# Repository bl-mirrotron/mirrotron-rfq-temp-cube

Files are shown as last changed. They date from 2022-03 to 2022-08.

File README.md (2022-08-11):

# RFQ Temperature Cube
* <a href="https://github.com/bl-mirrotron/mirrotron-rfq-temp-cube" target="_blank">Source code</a>
* [Cooling system overview](https://docs.bl-mirrotron.com/#cooling-system)
* [Control system overview](https://docs.bl-mirrotron.com/)

The function of the RFQ Temperature Cube is to measure the temperature of the cooling channels on both the upstream and downstream headers. The temperature is measured with <a href="https://www.maximintegrated.com/en/products/sensors/DS18B20.html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,for%20an%20external%20power%20supply." target="_blank">DS18B20</a> One-wire probes connected to a <a href="https://www.pjrc.com/teensy/teensyLC.html" target="_blank">Teensy-LC</a> as the micro-controller. The Teensy-LC communicates to a Blinky-Lite<sup>TM</sup> tray via the <a href="https://github.com/bl-mirrotron/mirrotron-rfq-temp-cube/blob/master/cubeCode/BlinkyBus.h" target="_blank">Blinky-Bus protocol</a> over the Serial1 port.

The schematic for the electrical circuit is shown in Figure 1. The board is designed to handle up to eight probes with each probe having it's own on/off power control if a individual channel needs a reboot. The PCB layout for the electrical circuit is shown in Figure 2. There is a 2x20 pin header mounted on the back of the PCB so that the cube can be directly mounted to a Raspberry Pi header for power and communications. 5V power to the Teensy-LC is provided through the header from Raspberry Pi. A manufactured board is shown in Figure 3.

<p style="text-align:center;font-size: large;"><span style="font-weight: bold;color: green;">Figure 1. </span> <span style="font-style: italic;">Electrical Schematic for rfq-temp-cube board</span></p>
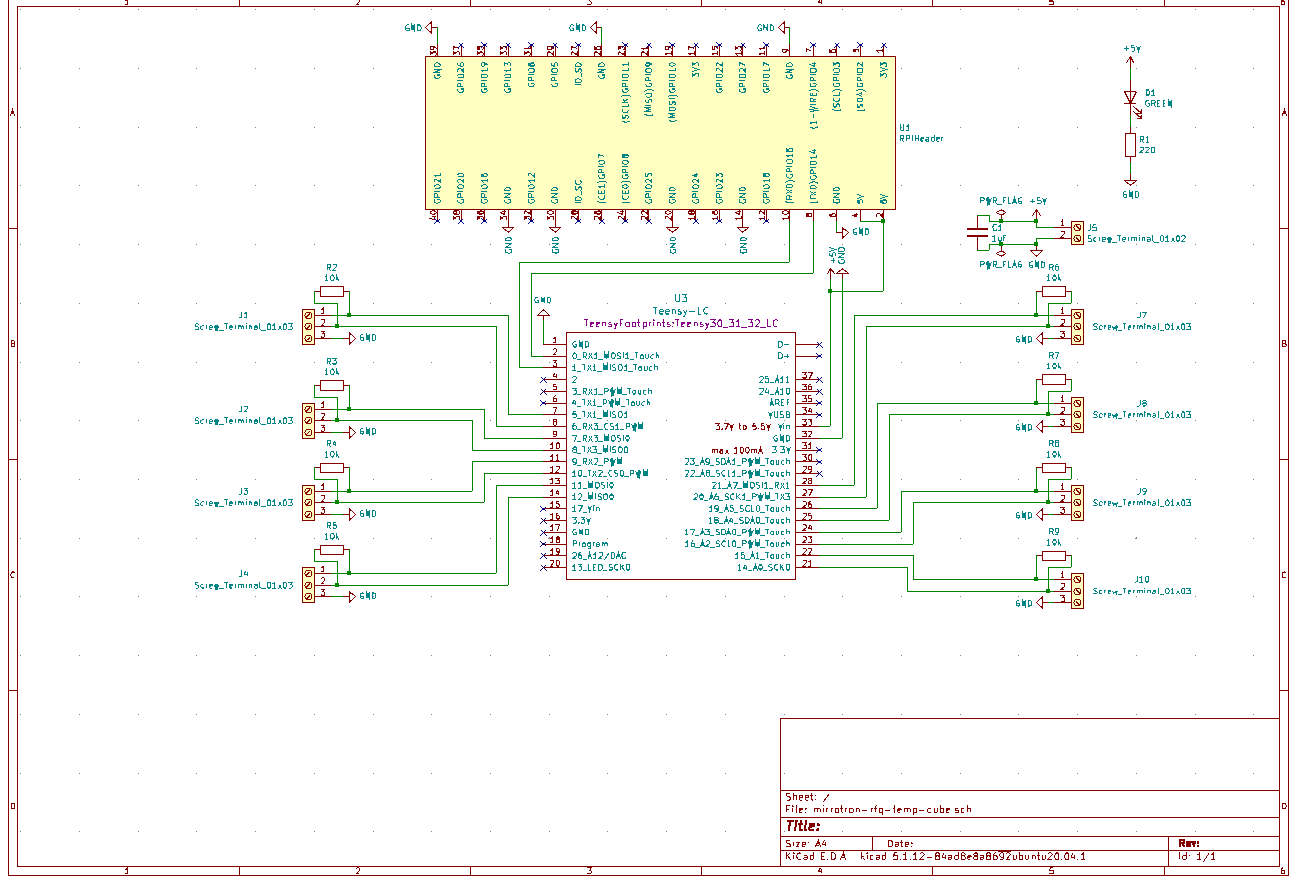
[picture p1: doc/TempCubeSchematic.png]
<br>

<p style="text-align:center;font-size: large;"><span style="font-weight: bold;color: green;">Figure 2. </span> <span style="font-style: italic;">PCB layout for rfq-temp-cube board</span></p>
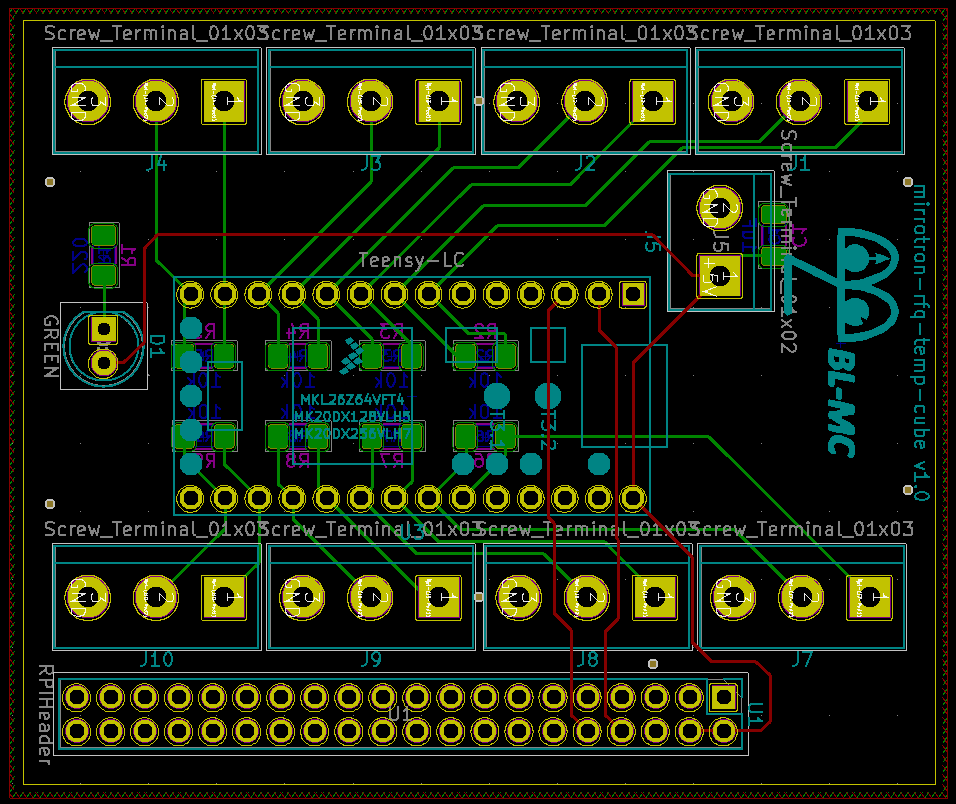
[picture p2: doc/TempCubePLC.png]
<br>

<p style="text-align:center;font-size: large;"><span style="font-weight: bold;color: green;">Figure 3. </span> <span style="font-style: italic;">rfq-temp-cube</span></p>
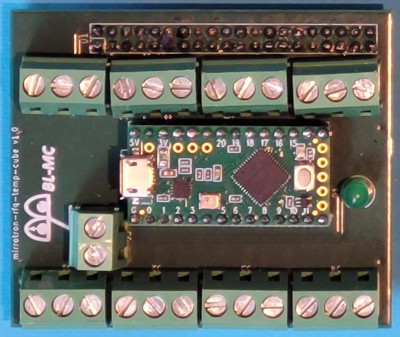
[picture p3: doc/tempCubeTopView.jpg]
<br>

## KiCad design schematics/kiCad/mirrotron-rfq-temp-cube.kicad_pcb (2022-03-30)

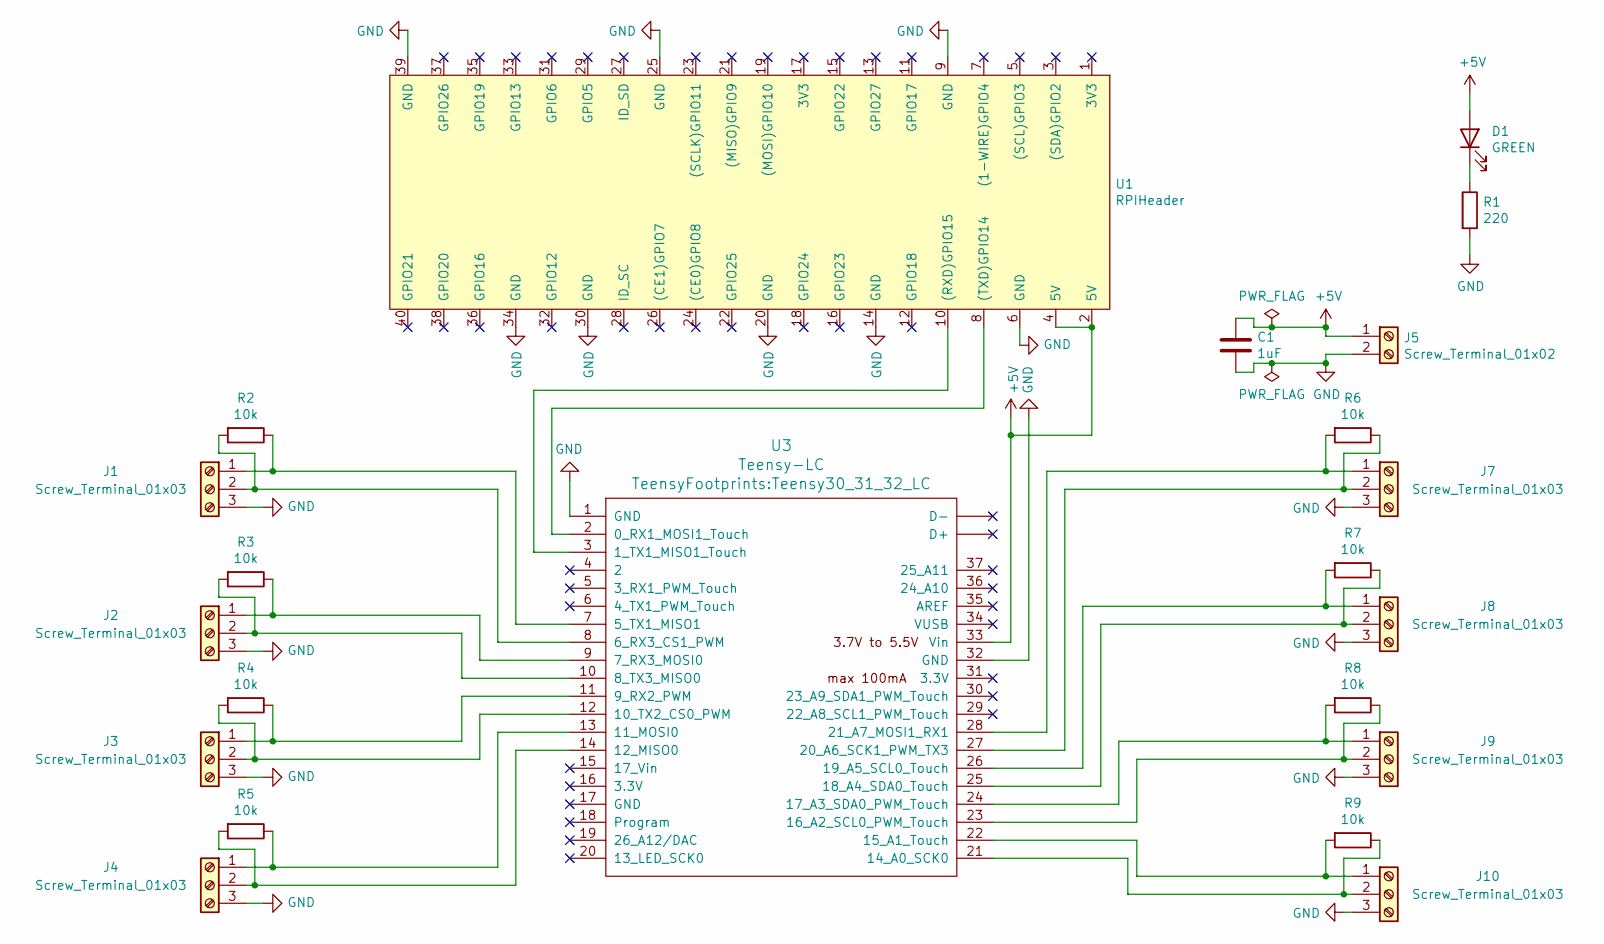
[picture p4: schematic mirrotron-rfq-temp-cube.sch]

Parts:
C1: 1uF; C_1206_3216Metric_Pad1.33x1.80mm_HandSolder
D1: GREEN; LED_D5.0mm
J1, J2, J3, J4, J7, J8, J9, J10: Screw_Terminal_01x03; TerminalBlock_bornier-3_P5.08mm
J5: Screw_Terminal_01x02; TerminalBlock_bornier-2_P5.08mm
R1: 220; R_1206_3216Metric_Pad1.42x1.75mm_HandSolder
R2, R3, R4, R5, R6, R7, R8, R9: 10k; R_1206_3216Metric_Pad1.42x1.75mm_HandSolder
U1: RPIHeader; PinHeader_2x20_P2.54mm_Vertical
U3: Teensy-LC; Teensy30_31_32_LC

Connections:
+5V: C1.1, D1.2 (A), J5.1, U1.2 (5V), U1.4 (5V), U3.33 (Vin)
GND: C1.2, J1.3, J2.3, J3.3, J4.3, J5.2, J7.3, J8.3, J9.3, J10.3, R1.2, U1.6 (GND), U1.9 (GND), U1.14 (GND), U1.20 (GND), U1.25 (GND), U1.30 (GND), U1.34 (GND), U1.39 (GND), U3.1 (GND), U3.32 (GND)
unnamed: D1.1 (K), R1.1
unnamed: J1.1, R2.1, U3.7 (5_TX1_MISO1)
unnamed: J1.2, R2.2, U3.8 (6_RX3_CS1_PWM)
unnamed: J2.1, R3.1, U3.9 (7_RX3_MOSI0)
unnamed: J2.2, R3.2, U3.10 (8_TX3_MISO0)
unnamed: J3.1, R4.1, U3.11 (9_RX2_PWM)
unnamed: J3.2, R4.2, U3.12 (10_TX2_CS0_PWM)
unnamed: J4.1, R5.1, U3.13 (11_MOSI0)
unnamed: J4.2, R5.2, U3.14 (12_MISO0)
unnamed: J7.1, R6.2, U3.28 (21_A7_MOSI1_RX1)
unnamed: J7.2, R6.1, U3.27 (20_A6_SCK1_PWM_TX3)
unnamed: J8.1, R7.2, U3.26 (19_A5_SCL0_Touch)
unnamed: J8.2, R7.1, U3.25 (18_A4_SDA0_Touch)
unnamed: J9.1, R8.2, U3.24 (17_A3_SDA0_PWM_Touch)
unnamed: J9.2, R8.1, U3.23 (16_A2_SCL0_PWM_Touch)
unnamed: J10.1, R9.2, U3.22 (15_A1_Touch)
unnamed: J10.2, R9.1, U3.21 (14_A0_SCK0)
unnamed: U1.8 ((TXD)GPIO14), U3.2 (0_RX1_MOSI1_Touch)
unnamed: U1.10 ((RXD)GPIO15), U3.3 (1_TX1_MISO1_Touch)

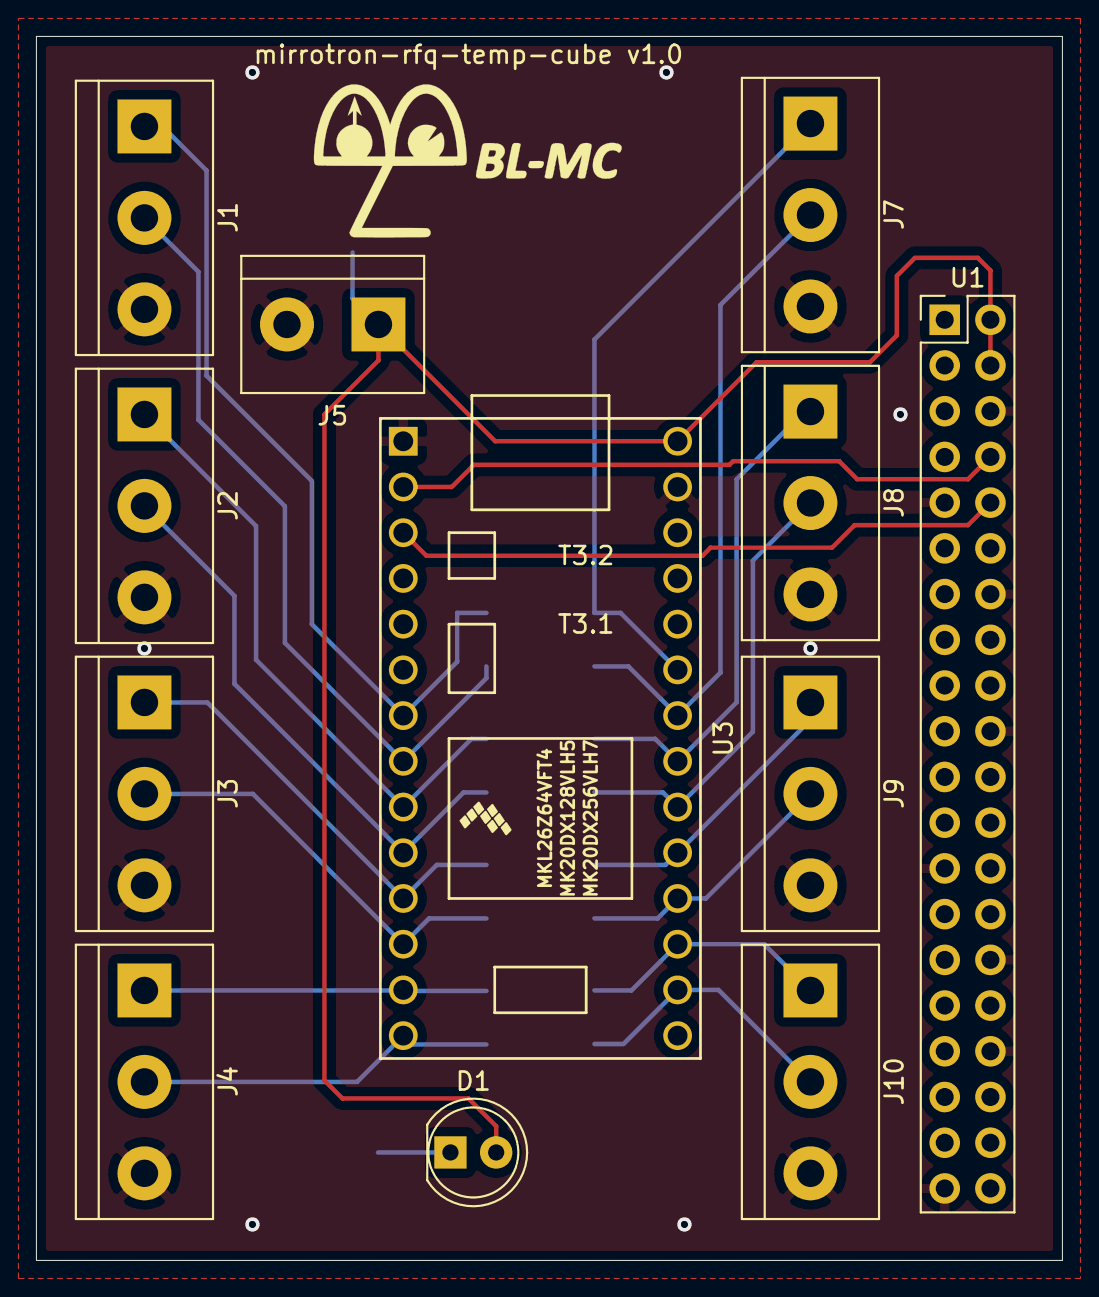
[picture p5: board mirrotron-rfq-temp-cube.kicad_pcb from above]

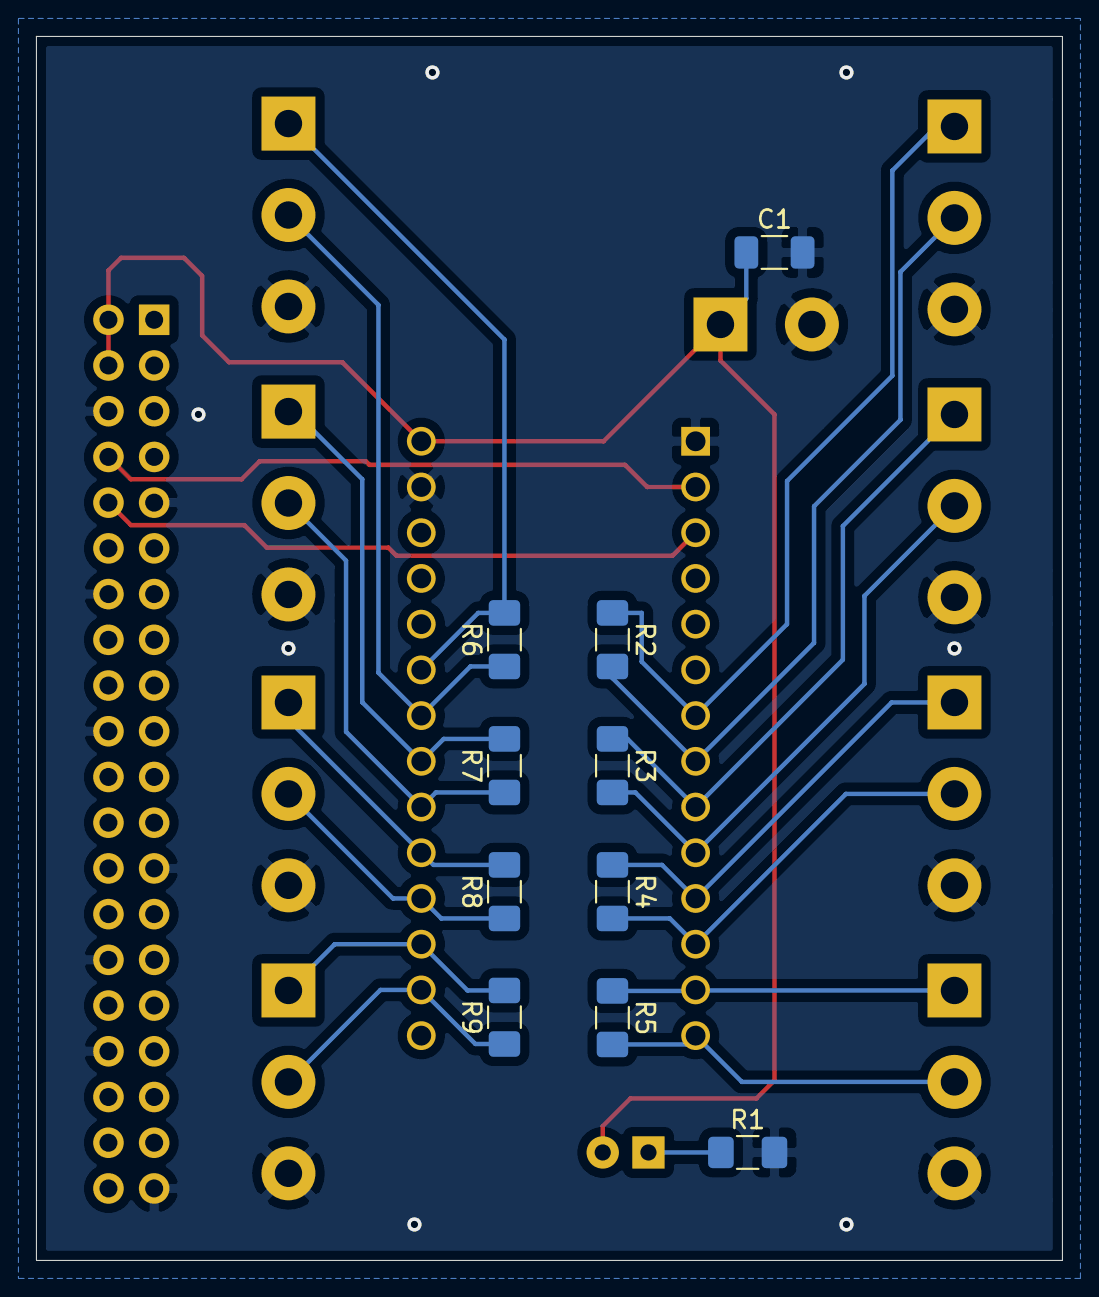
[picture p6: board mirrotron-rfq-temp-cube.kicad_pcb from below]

Board: 2 copper layers, 57.0 x 68.0 mm, 22 parts (10 on the bottom side), 21 nets.

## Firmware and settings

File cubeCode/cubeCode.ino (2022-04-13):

#include "BlinkyBus.h"
#include <OneWire.h>
#define BAUD_RATE  19200
#define commLEDPin    13
#define waitLOW 500
#define waitHIGH 500
#define waitMEAS 1000

#define BLINKYBUSBUFSIZE  10
union BlinkyBusUnion
{
  struct
  {
    int16_t state;
    int16_t i16_temp1;
    int16_t i16_temp2;
    int16_t i16_temp3;
    int16_t i16_temp4;
    int16_t i16_temp5;
    int16_t i16_temp6;
    int16_t i16_temp7;
    int16_t i16_temp8;
    int16_t i16_watchdog;
  };
  int16_t buffer[BLINKYBUSBUFSIZE];
} bb;
BlinkyBus blinkyBus(bb.buffer, BLINKYBUSBUFSIZE, Serial1, commLEDPin);

struct DS18B20
{
  int signalPin;
  int powerPin;
  byte chipType;
  byte address[8];
  OneWire oneWire;
  float temp = 0.0;
};

DS18B20 dS18B20_1;
DS18B20 dS18B20_2;
DS18B20 dS18B20_3;
DS18B20 dS18B20_4;
DS18B20 dS18B20_5;
DS18B20 dS18B20_6;
DS18B20 dS18B20_7;
DS18B20 dS18B20_8;

void setup() 
{
  dS18B20_1.signalPin = 6;
  dS18B20_1.powerPin = 5;
  pinMode(dS18B20_1.powerPin, OUTPUT);

  dS18B20_2.signalPin = 8;
  dS18B20_2.powerPin = 7;
  pinMode(dS18B20_2.powerPin, OUTPUT);
  digitalWrite(dS18B20_2.powerPin, HIGH);    

  dS18B20_3.signalPin = 10;
  dS18B20_3.powerPin = 9;
  pinMode(dS18B20_3.powerPin, OUTPUT);
  digitalWrite(dS18B20_3.powerPin, HIGH);    

  dS18B20_4.signalPin = 12;
  dS18B20_4.powerPin = 11;
  pinMode(dS18B20_4.powerPin, OUTPUT);
  digitalWrite(dS18B20_4.powerPin, HIGH);   

  dS18B20_5.signalPin = 14;
  dS18B20_5.powerPin = 15;
  pinMode(dS18B20_5.powerPin, OUTPUT);
  digitalWrite(dS18B20_5.powerPin, HIGH);   

  dS18B20_6.signalPin = 16;
  dS18B20_6.powerPin = 17;
  pinMode(dS18B20_6.powerPin, OUTPUT);
  digitalWrite(dS18B20_6.powerPin, HIGH);   

  dS18B20_7.signalPin = 18;
  dS18B20_7.powerPin = 19;
  pinMode(dS18B20_7.powerPin, OUTPUT);
  digitalWrite(dS18B20_7.powerPin, HIGH);   

  dS18B20_8.signalPin = 20;
  dS18B20_8.powerPin = 21;
  pinMode(dS18B20_8.powerPin, OUTPUT);
  digitalWrite(dS18B20_8.powerPin, HIGH);   

  digitalWrite(dS18B20_1.powerPin, LOW);    
  digitalWrite(dS18B20_2.powerPin, LOW);    
  digitalWrite(dS18B20_3.powerPin, LOW);    
  digitalWrite(dS18B20_4.powerPin, LOW);    
  digitalWrite(dS18B20_5.powerPin, LOW);    
  digitalWrite(dS18B20_6.powerPin, LOW);    
  digitalWrite(dS18B20_7.powerPin, LOW);    
  digitalWrite(dS18B20_8.powerPin, LOW);    
  delay(1000);
  digitalWrite(dS18B20_1.powerPin, HIGH);    
  digitalWrite(dS18B20_2.powerPin, HIGH);    
  digitalWrite(dS18B20_3.powerPin, HIGH);    
  digitalWrite(dS18B20_4.powerPin, HIGH);    
  digitalWrite(dS18B20_5.powerPin, HIGH);    
  digitalWrite(dS18B20_6.powerPin, HIGH);    
  digitalWrite(dS18B20_7.powerPin, HIGH);    
  digitalWrite(dS18B20_8.powerPin, HIGH);    
  delay(2000);

  dS18B20_1.oneWire = OneWire(dS18B20_1.signalPin);
  dS18B20_1.chipType = initDS18B20(dS18B20_1.address, &dS18B20_1.oneWire);
  dS18B20_2.oneWire = OneWire(dS18B20_2.signalPin);
  dS18B20_2.chipType = initDS18B20(dS18B20_2.address, &dS18B20_2.oneWire);
  dS18B20_3.oneWire = OneWire(dS18B20_3.signalPin);
  dS18B20_3.chipType = initDS18B20(dS18B20_3.address, &dS18B20_3.oneWire);
  dS18B20_4.oneWire = OneWire(dS18B20_4.signalPin);
  dS18B20_4.chipType = initDS18B20(dS18B20_4.address, &dS18B20_4.oneWire);
  dS18B20_5.oneWire = OneWire(dS18B20_5.signalPin);
  dS18B20_5.chipType = initDS18B20(dS18B20_5.address, &dS18B20_5.oneWire);
  dS18B20_6.oneWire = OneWire(dS18B20_6.signalPin);
  dS18B20_6.chipType = initDS18B20(dS18B20_6.address, &dS18B20_6.oneWire);
  dS18B20_7.oneWire = OneWire(dS18B20_7.signalPin);
  dS18B20_7.chipType = initDS18B20(dS18B20_7.address, &dS18B20_7.oneWire);
  dS18B20_8.oneWire = OneWire(dS18B20_8.signalPin);
  dS18B20_8.chipType = initDS18B20(dS18B20_8.address, &dS18B20_8.oneWire);

  
  Serial1.begin(BAUD_RATE);
  bb.state = 1; //init
  bb.i16_watchdog = 0; //init
  blinkyBus.start();
  delay(5000);
  
  Serial.begin(9600);

}

void loop() 
{
    digitalWrite(dS18B20_1.powerPin, LOW);
    waitSome(waitLOW);    
    digitalWrite(dS18B20_1.powerPin, HIGH);
    waitSome(waitHIGH);    
    dS18B20_1.temp = getDS18B20Temperature(&dS18B20_1.oneWire, dS18B20_1.address, dS18B20_1.chipType);
    bb.i16_temp1  = (int16_t) (dS18B20_1.temp * 10.0);

    digitalWrite(dS18B20_2.powerPin, LOW);
    waitSome(waitLOW);    
    digitalWrite(dS18B20_2.powerPin, HIGH);
    waitSome(waitHIGH);    
    dS18B20_2.temp = getDS18B20Temperature(&dS18B20_2.oneWire, dS18B20_2.address, dS18B20_2.chipType);
    bb.i16_temp2  = (int16_t) (dS18B20_2.temp * 10.0);

    digitalWrite(dS18B20_3.powerPin, LOW);
    waitSome(waitLOW);    
    digitalWrite(dS18B20_3.powerPin, HIGH);
    waitSome(waitHIGH);    
    dS18B20_3.temp = getDS18B20Temperature(&dS18B20_3.oneWire, dS18B20_3.address, dS18B20_3.chipType);
    bb.i16_temp3  = (int16_t) (dS18B20_3.temp * 10.0);

    digitalWrite(dS18B20_4.powerPin, LOW);
    waitSome(waitLOW);    
    digitalWrite(dS18B20_4.powerPin, HIGH);
    waitSome(waitHIGH);    
    dS18B20_4.temp = getDS18B20Temperature(&dS18B20_4.oneWire, dS18B20_4.address, dS18B20_4.chipType);
    bb.i16_temp4  = (int16_t) (dS18B20_4.temp * 10.0);

    digitalWrite(dS18B20_5.powerPin, LOW);
    waitSome(waitLOW);    
    digitalWrite(dS18B20_5.powerPin, HIGH);
    waitSome(waitHIGH);    
    dS18B20_5.temp = getDS18B20Temperature(&dS18B20_5.oneWire, dS18B20_5.address, dS18B20_5.chipType);
    bb.i16_temp5  = (int16_t) (dS18B20_5.temp * 10.0);

    digitalWrite(dS18B20_6.powerPin, LOW);
    waitSome(waitLOW);    
    digitalWrite(dS18B20_6.powerPin, HIGH);
    waitSome(waitHIGH);    
    dS18B20_6.temp = getDS18B20Temperature(&dS18B20_6.oneWire, dS18B20_6.address, dS18B20_6.chipType);
    bb.i16_temp6  = (int16_t) (dS18B20_6.temp * 10.0);

    digitalWrite(dS18B20_7.powerPin, LOW);
    waitSome(waitLOW);    
    digitalWrite(dS18B20_7.powerPin, HIGH);
    waitSome(waitHIGH);    
    dS18B20_7.temp = getDS18B20Temperature(&dS18B20_7.oneWire, dS18B20_7.address, dS18B20_7.chipType);
    bb.i16_temp7  = (int16_t) (dS18B20_7.temp * 10.0);

    digitalWrite(dS18B20_8.powerPin, LOW);
    waitSome(waitLOW);    
    digitalWrite(dS18B20_8.powerPin, HIGH);
    waitSome(waitHIGH);    
    dS18B20_8.temp = getDS18B20Temperature(&dS18B20_8.oneWire, dS18B20_8.address, dS18B20_8.chipType);
    bb.i16_temp8  = (int16_t) (dS18B20_8.temp * 10.0);

    
    bb.i16_watchdog = bb.i16_watchdog + 1;
    if ( bb.i16_watchdog > 32760 ) bb.i16_watchdog = 0;


    Serial.print(bb.i16_temp1);
    Serial.print(" ");
    Serial.print(bb.i16_temp2);
    Serial.print(" ");
    Serial.print(bb.i16_temp3);
    Serial.print(" ");
    Serial.print(bb.i16_temp4);
    Serial.print(" ");
    Serial.print(bb.i16_temp5);
    Serial.print(" ");
    Serial.print(bb.i16_temp6);
    Serial.print(" ");
    Serial.print(bb.i16_temp7);
    Serial.print(" ");
    Serial.print(bb.i16_temp8);
    Serial.print(" ");
    Serial.print(bb.i16_watchdog);
    Serial.print(" ");
    Serial.println(" ");
}
void waitSome(unsigned long milliWait)
{
  unsigned long now;
  unsigned long startWait;
  now = millis();
  startWait = now;
  while ((now -startWait) < milliWait)
  {
    now = millis();
    blinkyBus.poll();
  }
  
}
byte initDS18B20(byte* addr, OneWire* ow)
{
  byte type_s = 0;
  if ( !ow->search(addr)) 
  {
    ow->reset_search();
    delay(250);
    return 0;
  }
   
  // the first ROM byte indicates which chip
  switch (addr[0]) 
  {
    case 0x10:
      type_s = 1;
      break;
    case 0x28:
      type_s = 0;
      break;
    case 0x22:
      type_s = 0;
      break;
    default:
      return 0;
  } 
  return type_s;
}
float getDS18B20Temperature(OneWire* ow, byte* addr, byte chipType)
{
  byte i;
  byte data[12];
  float celsius;
  ow->reset();
  ow->select(addr);
  ow->write(0x44, 1);        // start conversion, with parasite power on at the end
  
//  delay(750);     // maybe 750ms is enough, maybe not
  waitSome(waitMEAS);  
  ow->reset();
  ow->select(addr);    
  ow->write(0xBE);         // Read Scratchpad

  for ( i = 0; i < 9; i++) data[i] = ow->read();
  int16_t raw = (data[1] << 8) | data[0];
  if (chipType) 
  {
    raw = raw << 3; // 9 bit resolution default
    if (data[7] == 0x10)  raw = (raw & 0xFFF0) + 12 - data[6];
  }
  else 
  {
    byte cfg = (data[4] & 0x60);
    if (cfg == 0x00) raw = raw & ~7;  // 9 bit resolution, 93.75 ms
    else if (cfg == 0x20) raw = raw & ~3; // 10 bit res, 187.5 ms
    else if (cfg == 0x40) raw = raw & ~1; // 11 bit res, 375 ms
  }
  celsius = (float)raw / 16.0;
  return celsius;
  
}
